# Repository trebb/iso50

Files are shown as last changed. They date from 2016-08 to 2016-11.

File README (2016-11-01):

ISO50 -- a 50% DIY computer keyboard

There are two variants of the ISO50 keyboard: hand-wired and
PCB-based.  Files and directories that have "pcb" in their name are
part of the PCB-based variant.

The hardware part is covered in directory ./hardware.

Firmware is based on TMK (https://github.com/tmk/tmk_keyboard); see
directories ./firmware or ./firmware-pcb, respectively.

http://imgur.com/a/XgsYZ
http://imgur.com/a/m9RCg

The name of this project refers to the standard 105-key ISO keyboard
layout, reduced to 50 %.  It is not related to anything using the
photography-related connotation of the name.  It is not affiliated
with http://blog.iso50.com/.

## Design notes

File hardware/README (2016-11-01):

To build the keyboard, two laser-cut plates, an optional PCB, a
3D-printed frame, and a sticker that covers the screw heads and holes
on the bottom need to be made.

Files in this directory

- top-plate.dxf, bottom-plate.dxf, top-plate-pcb.dxf,
  bottom-plate-pcb.dxf

Files for laser cutting the plates.  Top should be 1.5 mm, bottom
1.0 mm (hand-wired) or 1.5 mm (PCB).

- top-plate-pcb-pcb.dxf

Helper file used for the KiCad project in ./pcb-top-plate/.

- frame.dxf, frame-pcb.dxf

Various shapes and parameters that are read by frame.scad or
frame-pcb.scad, respectively.  frame.dxf also contains a wiring
schema.

- frame.scad, frame-pcb.scad

Renders the (merely decorative) keyboard frame. 'make frame.stl' or
'make frame-pcb.stl' should create a 3D-printable .stl file.

- bottom-label-de.svg, bottom-label-pcb-de.svg

Legend image intended to be put onto the bottom of the keyboard.  'make
bottom-label-de.pdf' or 'make bottom-label-pcb-de.pdf' should create a
printable pdf that can be scaled to A4 size and printed on adhesive
film.

- foot-template.dxf

Template for cutting the bottom label, placing the adhesive feet, and
cutting an insulating layer that goes on top of the bottom plate.

- pcb-main/

KiCad project of the PCB.

- ./pcb-top-plate/, ./pcb-bottom-plate/

KiCad projects containing PCB-shaped alternatives to top-plate-pcb.dxf
and bottom-plate-dxf.

Software used

LibreCAD 2.08 (.dxf)
OpenSCAD 2015.03 (.stl)
Inkscape 0.9.1 (.svg)
KiCad r6904

Other parts:

- 52 Cherry-style switches

- 1 2u Costar stabilizer set

- USB cable: Mini for the hand-wiring, Micro for the PCB.

- An ISO keycap set that contains

  - 6 1.25u bottom row keys (most sets contain 7),

  - 7 1.5u bottom row keys (only a few keysets on the market contain
    that much), and

  - an asymmetrical, stepped CapsLock key

- 12 standoffs M2 x 6.3 mm (hand-wired) or M2 x 4.5 mm (PCB)

- 52 diodes 1N4148

- For the hand wiring:

  - Teensy 2.0

  - 3 LEDs, 3 resistors 330 Ohm

- For components of the PCB variant, consult the KiCad project in
  directory ./pcb-main.

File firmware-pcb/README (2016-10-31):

The PCB version of the ISO50 has its diodes oriented in a way that is
unusual for projects using TMK (cathodes connected to columns instead
of rows); see file matrix.c.

Building firmware .hex file:

$ make program

Upload firmware to keyboard (press reset button first):

$ make dfu

Suggested soldering points for connecting a USBasp programmer to an
assembled board:

-----------------------------------------
Pin    m32U4            USBasp  Soldering
name   pin              pin     point
-----  ---------------  ------  ---------
RESET  13               5       SW1
GND    5,15,23,43,35    8,10    SW1
VCC    2,7,14,24,34,44  2       R4
MOSI   10               1       column 7
MISO   11               9       R10
SCLK   9                7       column 6
-----------------------------------------

Installing a bootloader:

$ avrdude -c usbasp -pm32u4 -U flash:w:ATMega32U4-usbdevice_dfu-1_0_0.hex

Setting fuses:

$ avrdude -c usbasp -pm32u4 -U lfuse:w:0xff:m -U hfuse:w:0xd9:m -U efuse:w:0xf3:m

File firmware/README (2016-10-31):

Building firmware .hex file:

$ make program

Upload firmware to keyboard (press reset button):

$ make teensy

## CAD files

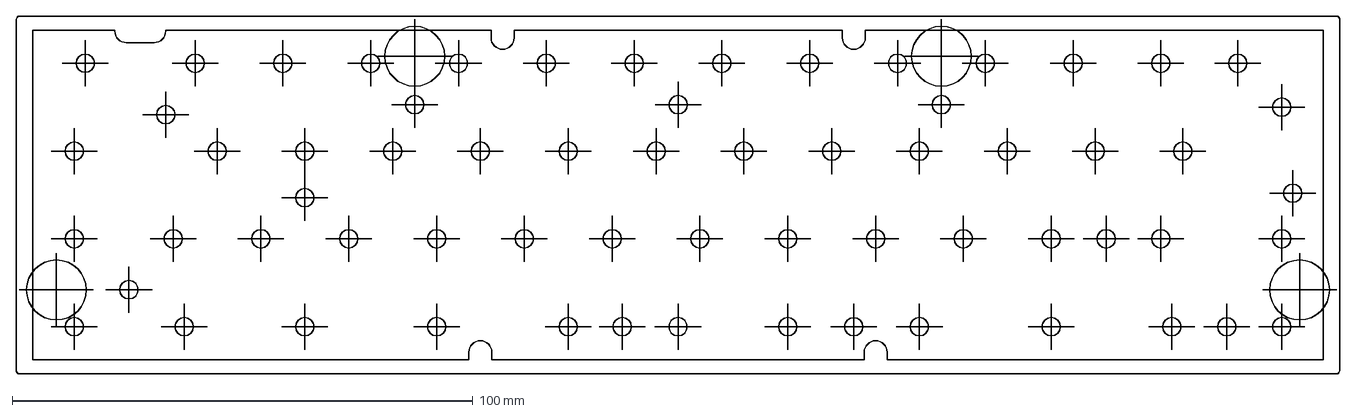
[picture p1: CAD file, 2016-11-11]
hardware/foot-template-pcb.dxf
287.2 x 77.6 mm

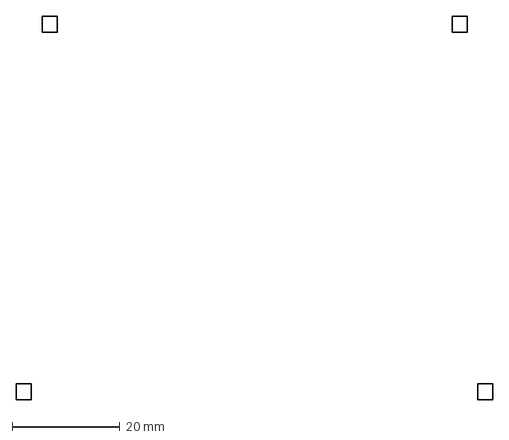
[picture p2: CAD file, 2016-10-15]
hardware/frame-pcb.dxf
88.6 x 71.1 mm

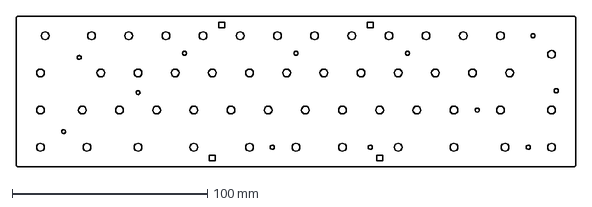
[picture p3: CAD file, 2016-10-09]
hardware/bottom-plate-pcb.dxf
286.8 x 77.2 mm

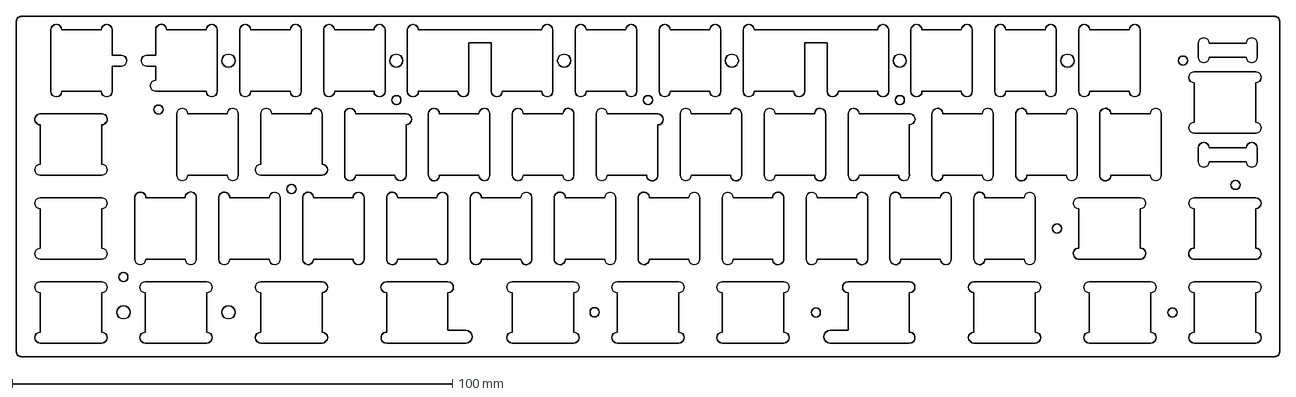
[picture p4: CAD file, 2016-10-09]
hardware/top-plate-pcb-pcb.dxf
286.8 x 77.2 mm

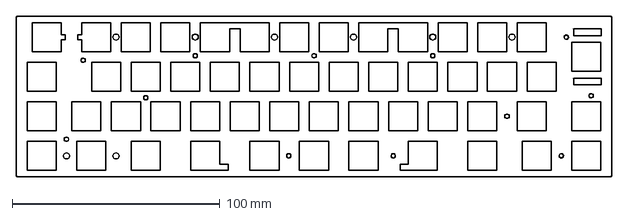
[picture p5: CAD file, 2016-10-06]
hardware/top-plate-pcb.dxf
286.8 x 77.2 mm

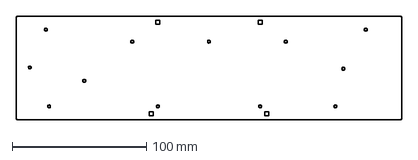
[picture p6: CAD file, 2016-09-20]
hardware/bottom-plate.dxf
286.8 x 77.2 mm

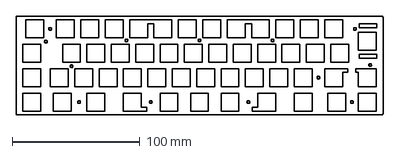
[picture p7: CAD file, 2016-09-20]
hardware/top-plate.dxf
286.8 x 77.2 mm

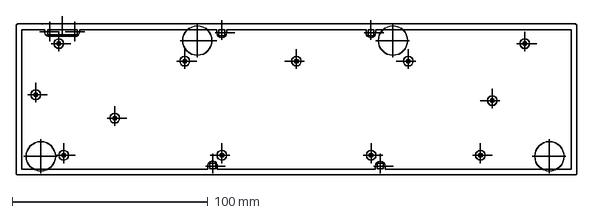
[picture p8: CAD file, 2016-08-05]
hardware/foot-template.dxf
286.8 x 81.2 mm

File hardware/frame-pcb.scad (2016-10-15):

h_key = dxf_dim(file="frame-pcb.dxf", name="key",
                layer="side-view", origin=[0, 0], scale=1);
h_top_plate = dxf_dim(file="frame-pcb.dxf", name="tpl",
                      layer="side-view", origin=[0, 0], scale=1);
h_mid = dxf_dim(file="frame-pcb.dxf", name="mid",
                layer="side-view", origin=[0, 0], scale=1);
h_bottom_plate = dxf_dim(file="frame-pcb.dxf", name="bpl",
                         layer="side-view", origin=[0, 0], scale=1);
h_label_clearance = dxf_dim(file="frame-pcb.dxf", name="lbl",
                layer="side-view", origin=[0, 0], scale=1);
x0_cable = dxf_dim(file="frame-pcb.dxf", name="x0cable",
                layer="cable", origin=[0, 0], scale=1);
y0_cable = dxf_dim(file="frame-pcb.dxf", name="y0cable",
                layer="cable", origin=[0, 0], scale=1);
delta_cx = dxf_dim(file="frame-pcb.dxf", name="delta_cx",
                   layer="cable", origin=[0, 0], scale=1);
delta_cy = dxf_dim(file="frame-pcb.dxf", name="delta_cy",
                   layer="cable", origin=[0, 0], scale=1);
epsilon = 1;

difference() {
  union() {
    difference() {
      hull() {
        /* color("green") { */
        color("green", $fs = 0.2, $fa = 2) {
          rotate_extrude() {
            import (file = "frame-pcb.dxf", layer = "outline-profile");
          }
          translate([delta_cx, 0, 0]) {
            rotate_extrude() {
              import (file = "frame-pcb.dxf", layer = "outline-profile");
            }
          }
          translate([delta_cx, delta_cy, 0]) {
            rotate_extrude() {
              import (file = "frame-pcb.dxf", layer = "outline-profile");
            }
          }
          translate([0, delta_cy, 0]) {
            rotate_extrude() {
              import (file = "frame-pcb.dxf", layer = "outline-profile");
            }
          }
        }
      }
      color("red") {
        translate([0, 0, -h_bottom_plate - h_label_clearance - epsilon]) {
          linear_extrude(height = h_key + h_top_plate + h_mid + h_bottom_plate + h_label_clearance + 2 * epsilon) {
            import (file = "frame-pcb.dxf", layer = "outline");
          }
        }
      }
    }
    translate([0, 0, -h_bottom_plate]) {
      linear_extrude(height = h_bottom_plate + h_mid + h_top_plate) {
        import (file = "frame-pcb.dxf", layer = "hooks");
      }
    }
    translate([0, 0, 0]) {
      linear_extrude(height = h_mid) {
        import (file = "frame-pcb.dxf", layer = "plate-support");
      }
    }
  }
  /* color("cyan") { */
  color("cyan", $fs = 0.2, $fa = 2) {
    translate([x0_cable, y0_cable, 0]) {
      rotate([-90, 0, 0]) {
        rotate_extrude() {
          import (file = "frame-pcb.dxf", layer = "cable-shape");
        }
      }
    }
  }
  translate([delta_cx - x0_cable, y0_cable + 2, (h_label_clearance + h_bottom_plate + h_mid + h_top_plate + h_key) / 2 - (h_label_clearance + h_bottom_plate)]) {
    rotate([90, 0, 180]) {
      linear_extrude(height = 5) {
        text("ISO50", halign = "left", valign = "center", font = "DejaVu Sans:style=Bold", size = 6, spacing = 1.1);
      }
    }
  }
  translate([x0_cable, y0_cable + 15, 0]) {
    rotate([90, 0, 0]) {
      linear_extrude(height = 30) {
        import (file = "frame-pcb.dxf", layer = "cable-chamfer");
      }
    }
  }
}

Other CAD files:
hardware/frame.dxf
hardware/frame.scad

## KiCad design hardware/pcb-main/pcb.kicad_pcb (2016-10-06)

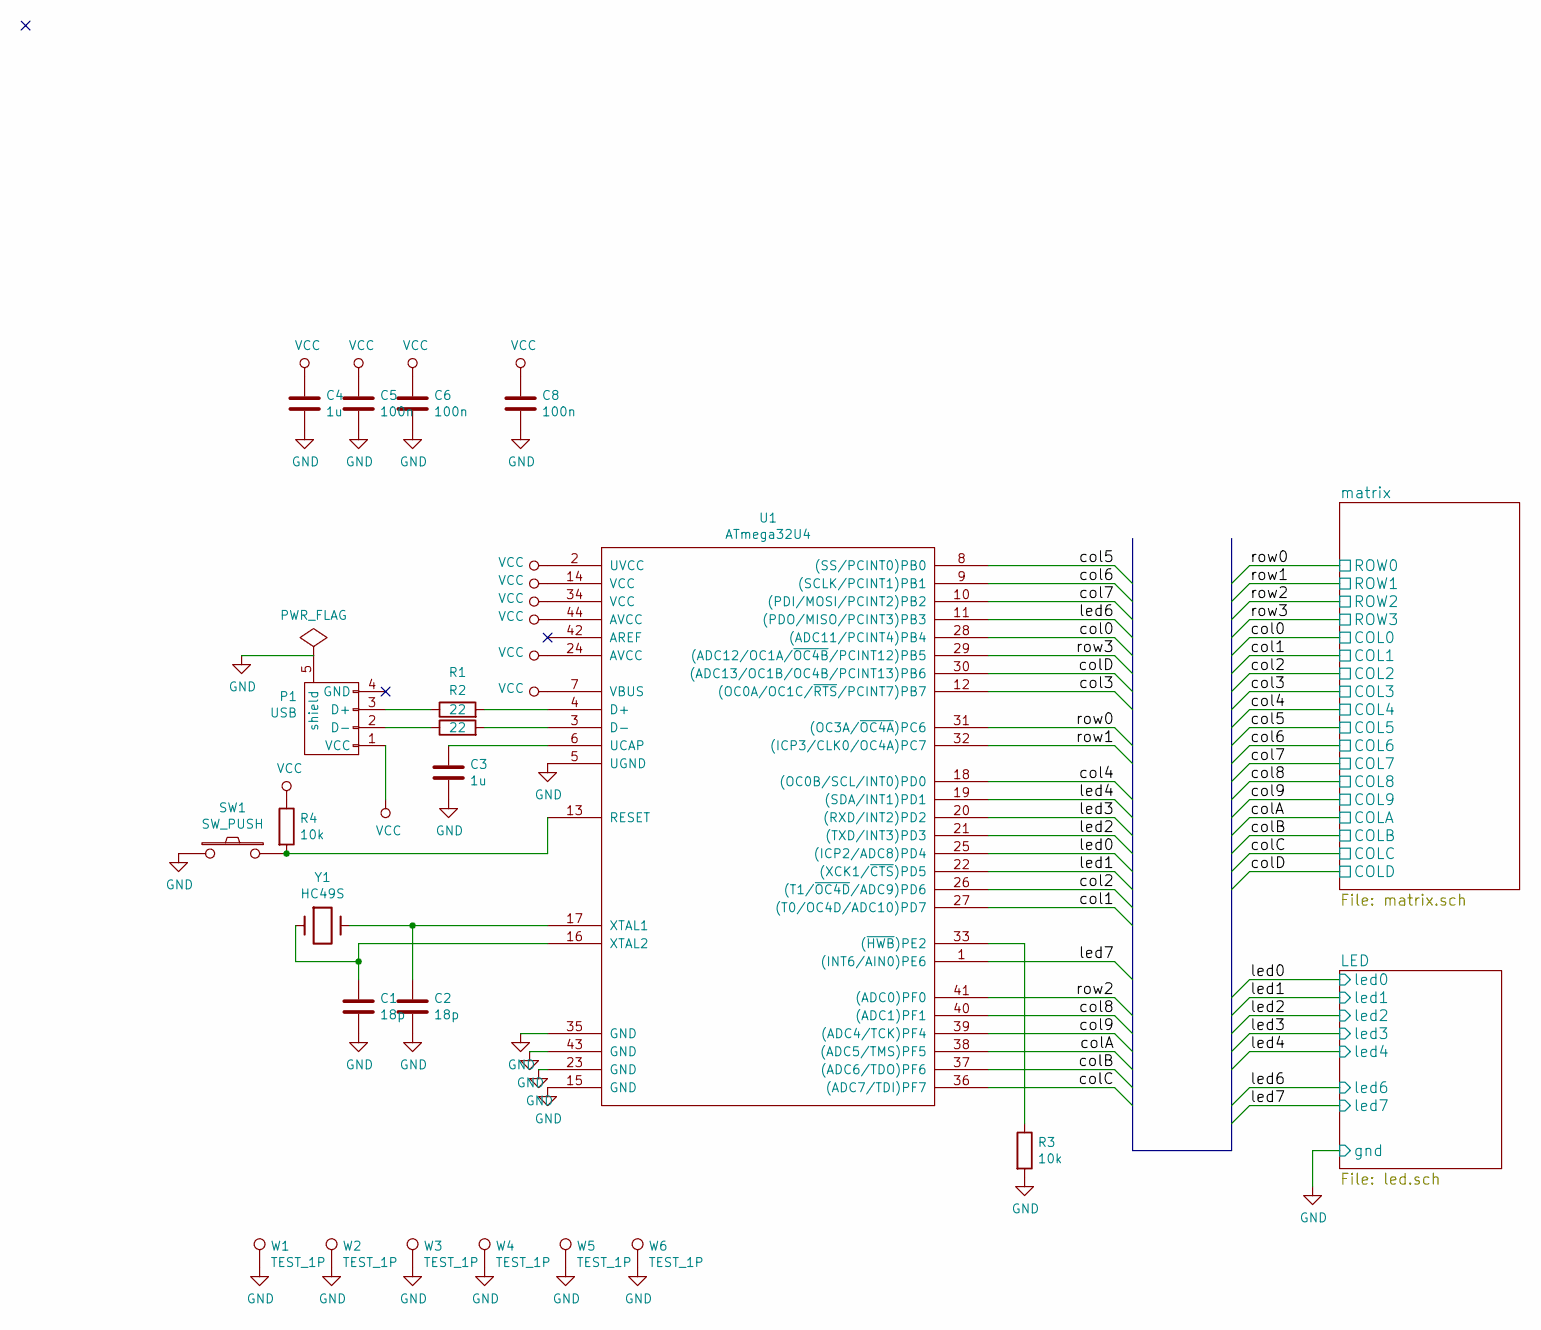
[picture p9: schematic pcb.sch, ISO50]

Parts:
C1, C2: 18p; C_1206_HandSoldering
C3, C4: 1u; C_1206_HandSoldering
C5, C6, C8: 100n; C_1206_HandSoldering
P1: USB; USB_Micro-207A-BBA0-R
R1, R2: 22; Resistor_Horizontal_RM7mm
R3, R4: 10k; Resistor_Horizontal_RM7mm
SW1: SW_PUSH; SW_PUSH_SMALL
U1: ATmega32U4; MLF-44_Atmel
W1, W2, W3, W4, W5, W6: TEST_1P; Spring-Contact_SMD
Y1: HC49S; Crystal_HC49-U_Vertical

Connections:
/col0: U1.28 ((ADC11/PCINT4)PB4); also elsewhere on the board
/col1: U1.27 ((T0/OC4D/ADC10)PD7); also elsewhere on the board
/col2: U1.26 ((T1/~OC4D~/ADC9)PD6); also elsewhere on the board
/col3: U1.12 ((OC0A/OC1C/~RTS~/PCINT7)PB7); also elsewhere on the board
/col4: U1.18 ((OC0B/SCL/INT0)PD0); also elsewhere on the board
/col5: U1.8 ((SS/PCINT0)PB0); also elsewhere on the board
/col6: U1.9 ((SCLK/PCINT1)PB1); also elsewhere on the board
/col7: U1.10 ((PDI/MOSI/PCINT2)PB2); also elsewhere on the board
/col8: U1.40 ((ADC1)PF1); also elsewhere on the board
/col9: U1.39 ((ADC4/TCK)PF4); also elsewhere on the board
/colA: U1.38 ((ADC5/TMS)PF5); also elsewhere on the board
/colB: U1.37 ((ADC6/TDO)PF6); also elsewhere on the board
/colC: U1.36 ((ADC7/TDI)PF7); also elsewhere on the board
/colD: U1.30 ((ADC13/OC1B/OC4B/PCINT13)PB6); also elsewhere on the board
/led0: U1.25 ((ICP2/ADC8)PD4); also elsewhere on the board
/led1: U1.22 ((XCK1/~CTS~)PD5); also elsewhere on the board
/led2: U1.21 ((TXD/INT3)PD3); also elsewhere on the board
/led3: U1.20 ((RXD/INT2)PD2); also elsewhere on the board
/led4: U1.19 ((SDA/INT1)PD1); also elsewhere on the board
/led6: U1.11 ((PDO/MISO/PCINT3)PB3); also elsewhere on the board
/led7: U1.1 ((INT6/AIN0)PE6); also elsewhere on the board
/row0: U1.31 ((OC3A/~OC4A~)PC6); also elsewhere on the board
/row1: U1.32 ((ICP3/CLK0/OC4A)PC7); also elsewhere on the board
/row2: U1.41 ((ADC0)PF0); also elsewhere on the board
/row3: U1.29 ((ADC12/OC1A/~OC4B~/PCINT12)PB5); also elsewhere on the board
GND: C1.2, C2.2, C3.2, C4.2, C5.2, C6.2, C8.2, P1.5 (shield), R3.2, SW1.2, U1.5 (UGND), U1.15 (GND), U1.23 (GND), U1.35 (GND), U1.43 (GND), W1.1, W2.1, W3.1, W4.1, W5.1, W6.1; also elsewhere on the board
unnamed: C1.1, U1.16 (XTAL2), Y1.1
unnamed: C2.1, U1.17 (XTAL1), Y1.2
unnamed: C3.1, U1.6 (UCAP)
unnamed: P1.2 (D-), R2.1
unnamed: P1.3 (D+), R1.1
unnamed: R1.2, U1.4 (D+)
unnamed: R2.2, U1.3 (D-)
unnamed: R3.1, U1.33 ((~HWB~)PE2)
unnamed: R4.2, SW1.1, U1.13 (RESET)
VCC: C4.1, C5.1, C6.1, C8.1, P1.1 (VCC), R4.1, U1.2 (UVCC), U1.7 (VBUS), U1.14 (VCC), U1.24 (AVCC), U1.34 (VCC), U1.44 (AVCC)

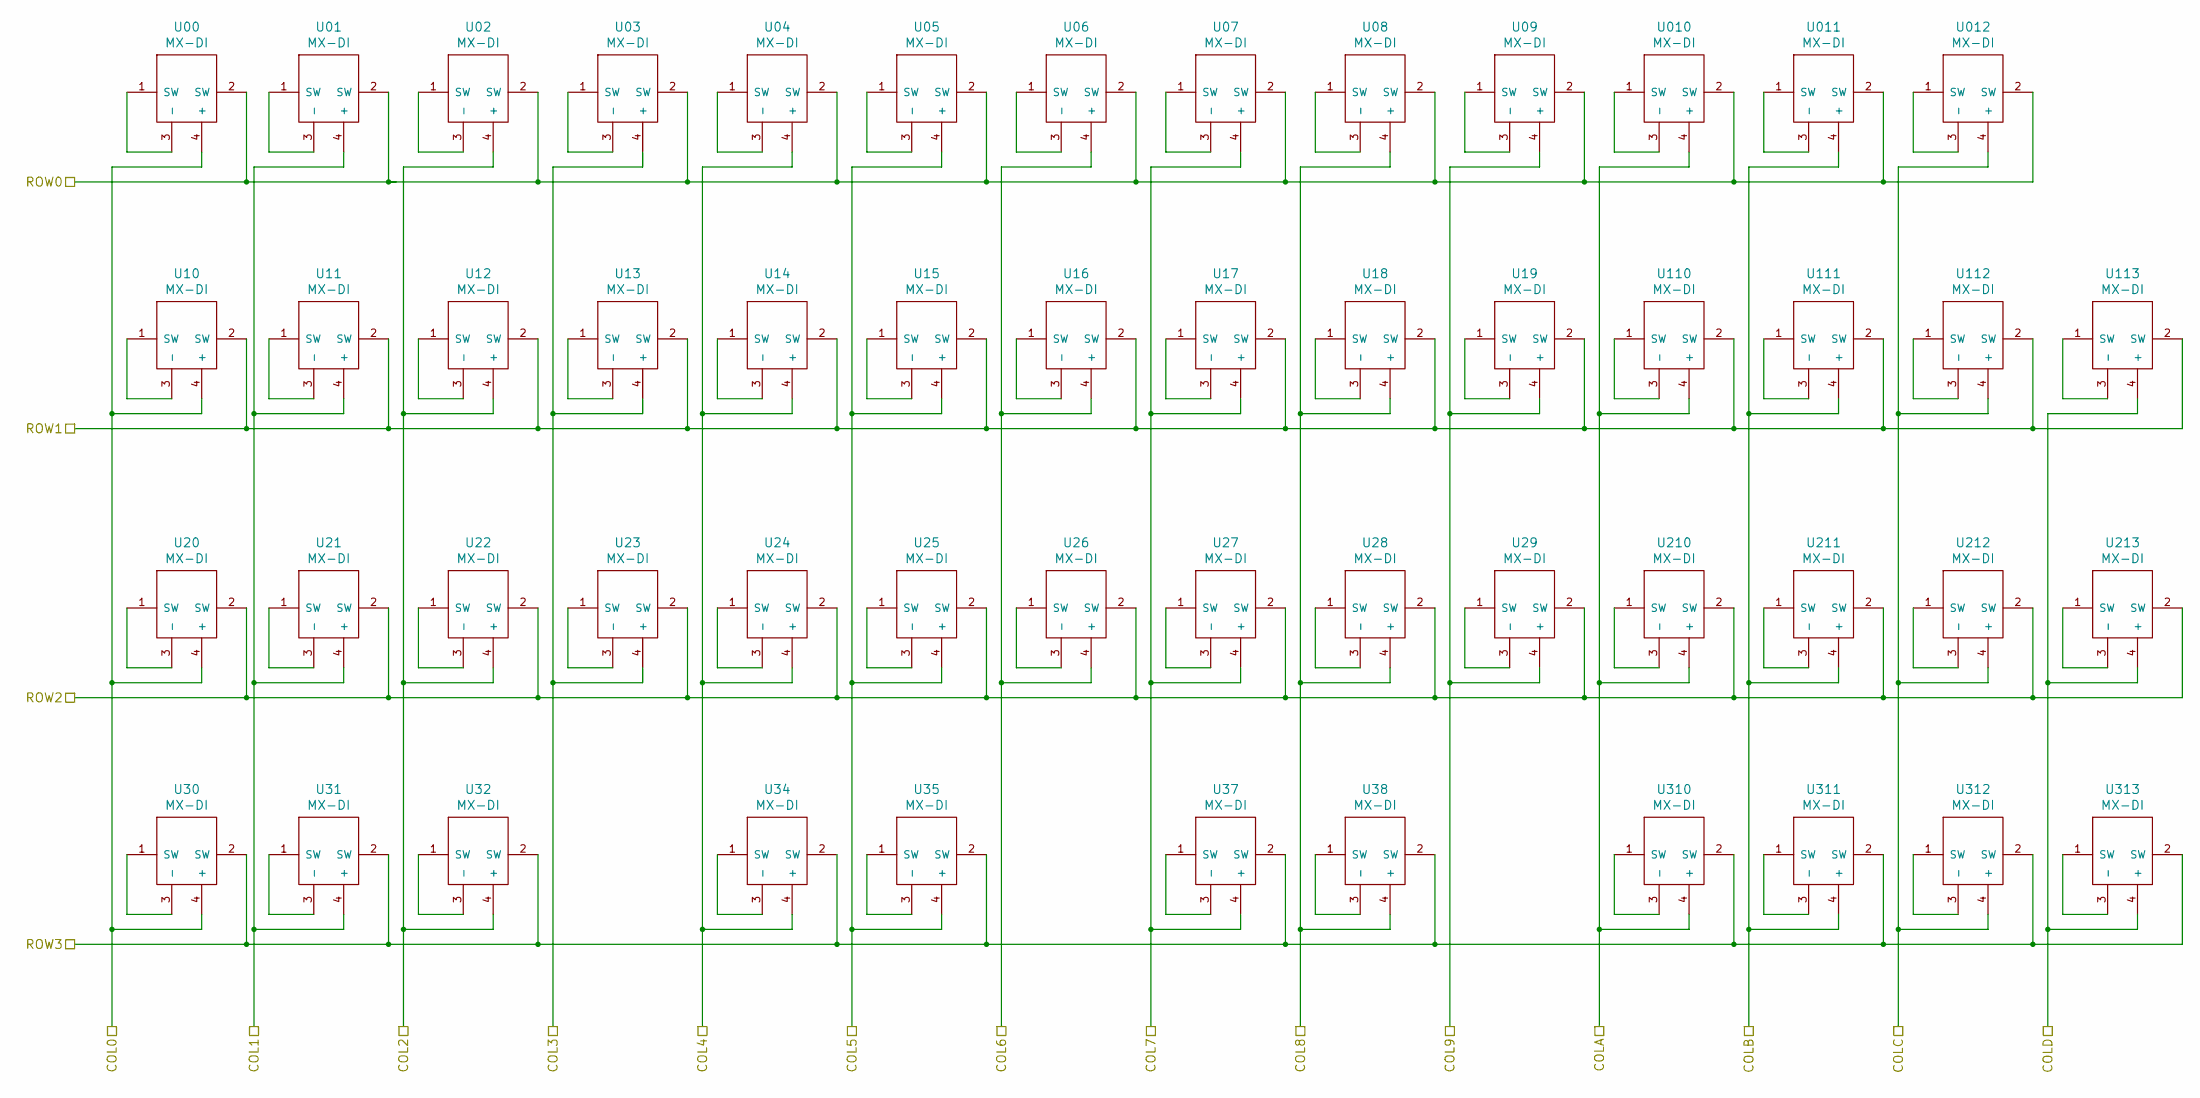
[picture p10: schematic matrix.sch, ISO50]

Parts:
U00, U01, U02, U03, U04, U05, U06, U07, U08, U09, U010, U10, U011, U11, U012, U12, U13, U14, U15, U16, U17, U18, U19, U20, U21, U22, U23, U24, U25, U26, U27, U28, U29, U30, U31, U32, U34, U35, U37, U38, U110, U111, U112, U113, U210, U211, U212, U213, U310, U311, U312, U313: MX-DI; MXDIODE

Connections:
/col0: U00.4 (+), U10.4 (+), U20.4 (+), U30.4 (+); also elsewhere on the board
/col1: U01.4 (+), U11.4 (+), U21.4 (+), U31.4 (+); also elsewhere on the board
/col2: U02.4 (+), U12.4 (+), U22.4 (+), U32.4 (+); also elsewhere on the board
/col3: U03.4 (+), U13.4 (+), U23.4 (+); also elsewhere on the board
/col4: U04.4 (+), U14.4 (+), U24.4 (+), U34.4 (+); also elsewhere on the board
/col5: U05.4 (+), U15.4 (+), U25.4 (+), U35.4 (+); also elsewhere on the board
/col6: U06.4 (+), U16.4 (+), U26.4 (+); also elsewhere on the board
/col7: U07.4 (+), U17.4 (+), U27.4 (+), U37.4 (+); also elsewhere on the board
/col8: U08.4 (+), U18.4 (+), U28.4 (+), U38.4 (+); also elsewhere on the board
/col9: U09.4 (+), U19.4 (+), U29.4 (+); also elsewhere on the board
/colA: U010.4 (+), U110.4 (+), U210.4 (+), U310.4 (+); also elsewhere on the board
/colB: U011.4 (+), U111.4 (+), U211.4 (+), U311.4 (+); also elsewhere on the board
/colC: U012.4 (+), U112.4 (+), U212.4 (+), U312.4 (+); also elsewhere on the board
/colD: U113.4 (+), U213.4 (+), U313.4 (+); also elsewhere on the board
/row0: U00.2 (SW), U01.2 (SW), U02.2 (SW), U03.2 (SW), U04.2 (SW), U05.2 (SW), U06.2 (SW), U07.2 (SW), U08.2 (SW), U09.2 (SW), U010.2 (SW), U011.2 (SW), U012.2 (SW); also elsewhere on the board
/row1: U10.2 (SW), U11.2 (SW), U12.2 (SW), U13.2 (SW), U14.2 (SW), U15.2 (SW), U16.2 (SW), U17.2 (SW), U18.2 (SW), U19.2 (SW), U110.2 (SW), U111.2 (SW), U112.2 (SW), U113.2 (SW); also elsewhere on the board
/row2: U20.2 (SW), U21.2 (SW), U22.2 (SW), U23.2 (SW), U24.2 (SW), U25.2 (SW), U26.2 (SW), U27.2 (SW), U28.2 (SW), U29.2 (SW), U210.2 (SW), U211.2 (SW), U212.2 (SW), U213.2 (SW); also elsewhere on the board
/row3: U30.2 (SW), U31.2 (SW), U32.2 (SW), U34.2 (SW), U35.2 (SW), U37.2 (SW), U38.2 (SW), U310.2 (SW), U311.2 (SW), U312.2 (SW), U313.2 (SW); also elsewhere on the board
unnamed: U00.1 (SW), U00.3 (-)
unnamed: U01.1 (SW), U01.3 (-)
unnamed: U02.1 (SW), U02.3 (-)
unnamed: U03.1 (SW), U03.3 (-)
unnamed: U04.1 (SW), U04.3 (-)
unnamed: U05.1 (SW), U05.3 (-)
unnamed: U06.1 (SW), U06.3 (-)
unnamed: U07.1 (SW), U07.3 (-)
unnamed: U08.1 (SW), U08.3 (-)
unnamed: U09.1 (SW), U09.3 (-)
unnamed: U10.1 (SW), U10.3 (-)
unnamed: U010.1 (SW), U010.3 (-)
unnamed: U11.1 (SW), U11.3 (-)
unnamed: U011.1 (SW), U011.3 (-)
unnamed: U12.1 (SW), U12.3 (-)
unnamed: U012.1 (SW), U012.3 (-)
unnamed: U13.1 (SW), U13.3 (-)
unnamed: U14.1 (SW), U14.3 (-)
unnamed: U15.1 (SW), U15.3 (-)
unnamed: U16.1 (SW), U16.3 (-)
unnamed: U17.1 (SW), U17.3 (-)
unnamed: U18.1 (SW), U18.3 (-)
unnamed: U19.1 (SW), U19.3 (-)
unnamed: U20.1 (SW), U20.3 (-)
unnamed: U21.1 (SW), U21.3 (-)
unnamed: U22.1 (SW), U22.3 (-)
unnamed: U23.1 (SW), U23.3 (-)
unnamed: U24.1 (SW), U24.3 (-)
unnamed: U25.1 (SW), U25.3 (-)
unnamed: U26.1 (SW), U26.3 (-)
unnamed: U27.1 (SW), U27.3 (-)
unnamed: U28.1 (SW), U28.3 (-)
unnamed: U29.1 (SW), U29.3 (-)
unnamed: U30.1 (SW), U30.3 (-)
unnamed: U31.1 (SW), U31.3 (-)
unnamed: U32.1 (SW), U32.3 (-)
unnamed: U34.1 (SW), U34.3 (-)
unnamed: U35.1 (SW), U35.3 (-)
unnamed: U37.1 (SW), U37.3 (-)
unnamed: U38.1 (SW), U38.3 (-)
unnamed: U110.1 (SW), U110.3 (-)
unnamed: U111.1 (SW), U111.3 (-)
unnamed: U112.1 (SW), U112.3 (-)
unnamed: U113.1 (SW), U113.3 (-)
unnamed: U210.1 (SW), U210.3 (-)
unnamed: U211.1 (SW), U211.3 (-)
unnamed: U212.1 (SW), U212.3 (-)
unnamed: U213.1 (SW), U213.3 (-)
unnamed: U310.1 (SW), U310.3 (-)
unnamed: U311.1 (SW), U311.3 (-)
unnamed: U312.1 (SW), U312.3 (-)
unnamed: U313.1 (SW), U313.3 (-)

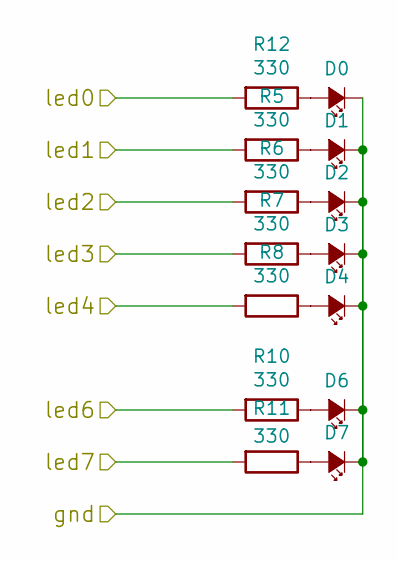
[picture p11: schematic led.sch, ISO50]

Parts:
D0, D1, D2, D3, D4, D6, D7: Led_Small; LED-3MM
R5, R6, R7, R8, R10, R11, R12: 330; Resistor_Horizontal_RM7mm

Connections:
/led0: R12.2; also elsewhere on the board
/led1: R5.2; also elsewhere on the board
/led2: R6.2; also elsewhere on the board
/led3: R7.2; also elsewhere on the board
/led4: R8.2; also elsewhere on the board
/led6: R10.2; also elsewhere on the board
/led7: R11.2; also elsewhere on the board
GND: D0.1 (K), D1.1 (K), D2.1 (K), D3.1 (K), D4.1 (K), D6.1 (K), D7.1 (K); also elsewhere on the board
unnamed: D0.2 (A), R12.1
unnamed: D1.2 (A), R5.1
unnamed: D2.2 (A), R6.1
unnamed: D3.2 (A), R7.1
unnamed: D4.2 (A), R8.1
unnamed: D6.2 (A), R10.1
unnamed: D7.2 (A), R11.1

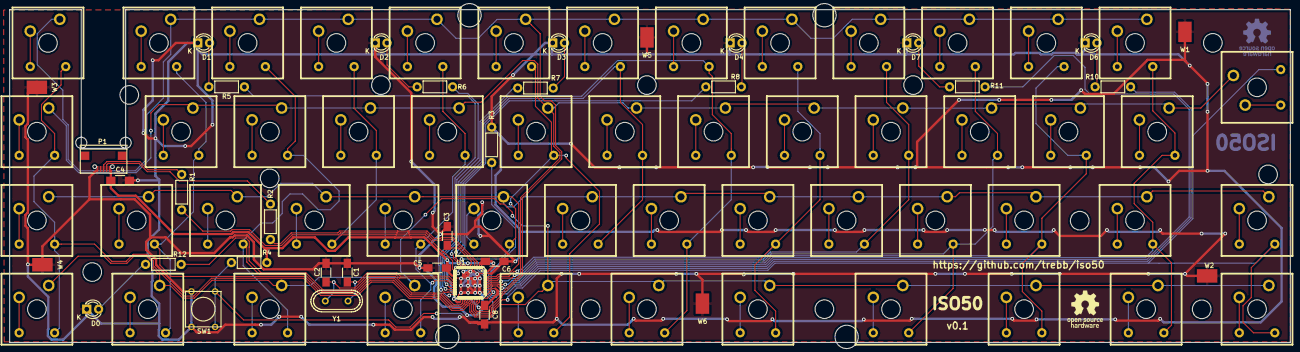
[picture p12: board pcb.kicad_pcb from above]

Board: 2 copper layers, 274.9 x 71.4 mm, 87 parts (0 on the bottom side), 95 nets.

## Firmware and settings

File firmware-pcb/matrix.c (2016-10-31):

/*
Copyright 2012 Jun Wako <wakojun@gmail.com>

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
You should have received a copy of the GNU General Public License
along with this program.  If not, see <http://www.gnu.org/licenses/>.
*/

/*
 * scan matrix
 */
#include <stdint.h>
#include <stdbool.h>
#include <avr/io.h>
#include <util/delay.h>
#include "print.h"
#include "debug.h"
#include "util.h"
#include "matrix.h"


#ifndef DEBOUNCE
#   define DEBOUNCE	5
#endif
static uint8_t debouncing = DEBOUNCE;

/* matrix state(1:on, 0:off) */
static matrix_row_t matrix[MATRIX_ROWS];
static matrix_row_t matrix_debouncing[MATRIX_ROWS];

static uint8_t read_rows(void);
static void init_rows(void);
static void unselect_cols(void);
static void select_col(uint8_t row);


inline uint8_t
matrix_rows(void)
{
    return MATRIX_ROWS;
}

inline uint8_t
matrix_cols(void)
{
    return MATRIX_COLS;
}

void
matrix_init(void)
{
    // initialize row and col
    unselect_cols();
    init_rows();

    // initialize matrix state: all keys off
    for (uint8_t i=0; i < MATRIX_ROWS; i++) {
        matrix[i] = 0;
        matrix_debouncing[i] = 0;
    }
}

uint8_t
matrix_scan(void)
{
    for (uint8_t col = 0; col < MATRIX_COLS; col++) {
        select_col(col);
        _delay_us(30);  // without this wait read unstable value.
        uint8_t rows = read_rows();
        for (uint8_t row = 0; row < MATRIX_ROWS; row++) {
            bool prev_bit = matrix_debouncing[row] & ((matrix_row_t)1<<col);
            bool curr_bit = rows & (1<<row);
            if (prev_bit != curr_bit) {
                matrix_debouncing[row] ^= ((matrix_row_t)1<<col);
                if (debouncing) {
                    debug("bounce!: "); debug_hex(debouncing); debug("\n");
                }
                debouncing = DEBOUNCE;
            }
            unselect_cols();
        }
    }

    if (debouncing) {
        if (--debouncing) {
            _delay_ms(1);
        } else {
            for (uint8_t i = 0; i < MATRIX_ROWS; i++) {
                matrix[i] = matrix_debouncing[i];
            }
        }
    }

    return 1;
}

bool
matrix_is_modified(void)
{
    if (debouncing) return false;
    return true;
}

inline bool
matrix_is_on(uint8_t row, uint8_t col)
{
    return (matrix[row] & ((matrix_row_t)1<<col));
}

inline matrix_row_t
matrix_get_row(uint8_t row)
{
    return matrix[row];
}

void
matrix_print(void)
{
    print("\nr/c 0123456789ABCDEF\n");
    for (uint8_t row = 0; row < MATRIX_ROWS; row++) {
        phex(row); print(": ");
        pbin_reverse16(matrix_get_row(row));
        print("\n");
    }
}

uint8_t
matrix_key_count(void)
{
    uint8_t count = 0;
    for (uint8_t i = 0; i < MATRIX_ROWS; i++) {
        count += bitpop16(matrix[i]);
    }
    return count;
}

/* Row pin configuration
 * row: 0  1  2  3
 * pin: C6 C7 F0 B5
 */
static void
init_rows(void)
{
    // Input with pull-up(DDR:0, PORT:1)
    DDRB  &= ~0b00100000;
    PORTB |=  0b00100000;
    DDRC  &= ~0b11000000;
    PORTC |=  0b11000000;
    DDRF  &= ~0b00000001;
    PORTF |=  0b00000001;
}

static uint8_t
read_rows(void)
{
    return
        (PINC&(1<<6) ? 0 : (1<<0)) |
        (PINC&(1<<7) ? 0 : (1<<1)) |
        (PINF&(1<<0) ? 0 : (1<<2)) |
        (PINB&(1<<5) ? 0 : (1<<3));
}


/* Column pin configuration
 * col: 0  1  2  3  4  5  6  7  8  9  A  B  C  D
 * pin: B4 D7 D6 B7 D0 B0 B1 B2 F1 F4 F5 F6 F7 B6
 */
static void
unselect_cols(void)
{
    // Hi-Z(DDR:0, PORT:0) to unselect
    DDRB  |= 0b11010111;
    PORTB |= 0b11010111;
    DDRD  |= 0b11000001;
    PORTD |= 0b11000001;
    DDRF  |= 0b11110010;
    PORTF |= 0b11110010;
}

static void
select_col(uint8_t col)
{
    // Output low(DDR:1, PORT:0) to select
    switch (col) {
        case 0x0:
            DDRB  |= (1<<4);
            PORTB &= ~(1<<4);
            break;
        case 0x1:
            DDRD  |= (1<<7);
            PORTD &= ~(1<<7);
            break;
        case 0x2:
            DDRD  |= (1<<6);
            PORTD &= ~(1<<6);
            break;
        case 0x3:
            DDRB  |= (1<<7);
            PORTB &= ~(1<<7);
            break;
        case 0x4:
            DDRD  |= (1<<0);
            PORTD &= ~(1<<0);
            break;
        case 0x5:
            DDRB  |= (1<<0);
            PORTB &= ~(1<<0);
            break;
        case 0x6:
            DDRB  |= (1<<1);
            PORTB &= ~(1<<1);
            break;
        case 0x7:
            DDRB  |= (1<<2);
            PORTB &= ~(1<<2);
            break;
        case 0x8:
            DDRF  |= (1<<1);
            PORTF &= ~(1<<1);
            break;
        case 0x9:
            DDRF  |= (1<<4);
            PORTF &= ~(1<<4);
            break;
        case 0xa:
            DDRF  |= (1<<5);
            PORTF &= ~(1<<5);
            break;
        case 0xb:
            DDRF  |= (1<<6);
            PORTF &= ~(1<<6);
            break;
        case 0xc:
            DDRF  |= (1<<7);
            PORTF &= ~(1<<7);
            break;
        case 0xd:
            DDRB  |= (1<<6);
            PORTB &= ~(1<<6);
            break;
    }
}

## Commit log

2016-07-30 Initial commit
    - Firmware compiles.
    - Completely untested.
    [foot-template.dxf, iso50-bottom.dxf, iso50-top.dxf]
2016-08-01 Initial design of a 3D-printable frame
    [frame.dxf, frame.scad]
2016-08-04 Add functionality and beauty to frame
    - Give it a more rounded shape.
    - Add a cable routing.
    - Add an "ISO50" imprint.
    [frame.dxf, frame.scad]
2016-08-04 Move hardware stuff into its own directory
    [foot-template.dxf, frame.dxf, frame.scad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]
2016-08-05 Draw an insulating layer
    It goes between switches and bottom plate.
    [foot-template.dxf]
2016-08-06 Add wiring plan
    [frame.dxf]
2016-08-07 Improve wiring plan
    [frame.dxf]
2016-08-07 In ./hardware/: rename files, add Makefile
    [bottom-plate.dxf, frame.dxf, top-plate.dxf]
2016-08-12 Reduce casing height by 0.7 mm
    [frame.dxf, frame.scad]
2016-08-14 Fix position of reset button on bottom label
2016-08-20 Wiring plan: position Teensy more realistically
    [frame.dxf]
2016-09-20 Fix bugs in CAD files
    - Reduce size of stabilizer holes.
    - Replace polygons by arcs and circles.
    - Move the reset hole.
    - Move a standoff position whose screw head collided with the
    stabilizer wire.
    [bottom-plate.dxf, top-plate.dxf]
2016-10-06 Add PCB
    [led.sch, matrix.sch, pcb.kicad_pcb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]
2016-10-06 Reduce PCB width
    [pcb.kicad_pcb]
2016-10-06 Add steel top plate for PCB version
    [top-plate-pcb.dxf]
2016-10-09 Add plates for the PCB version
    [bottom-plate-pcb.dxf, pcb-bottom-plate.kicad_pcb, pcb-bottom-plate.sch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]
2016-10-15 Add PCB version of 3D-printed frame
    [frame-pcb.dxf, frame-pcb.scad]
2016-10-28 Add PCB version of the bottom label
2016-10-31 Add PCB firmware
2016-10-31 We have an official USB VID/PID combination
    Thanks to http://pid.codes.
2016-10-31 Edit PCB version of bottom label
2016-11-06 Add template for cutting bottom label and insulating layer
    (Belongs to the PCB version of the keyboard.)
    [foot-template-pcb.dxf]
2016-11-11 Remove an unnecessary hole from foot template
    [foot-template-pcb.dxf]

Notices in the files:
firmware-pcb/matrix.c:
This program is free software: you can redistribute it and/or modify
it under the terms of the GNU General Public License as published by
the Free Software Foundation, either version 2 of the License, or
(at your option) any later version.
